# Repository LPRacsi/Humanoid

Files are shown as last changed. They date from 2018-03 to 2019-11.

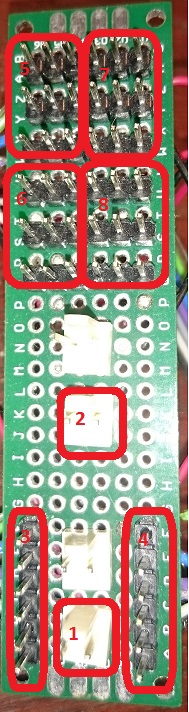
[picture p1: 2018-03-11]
Documentation/DSC_0448.JPG

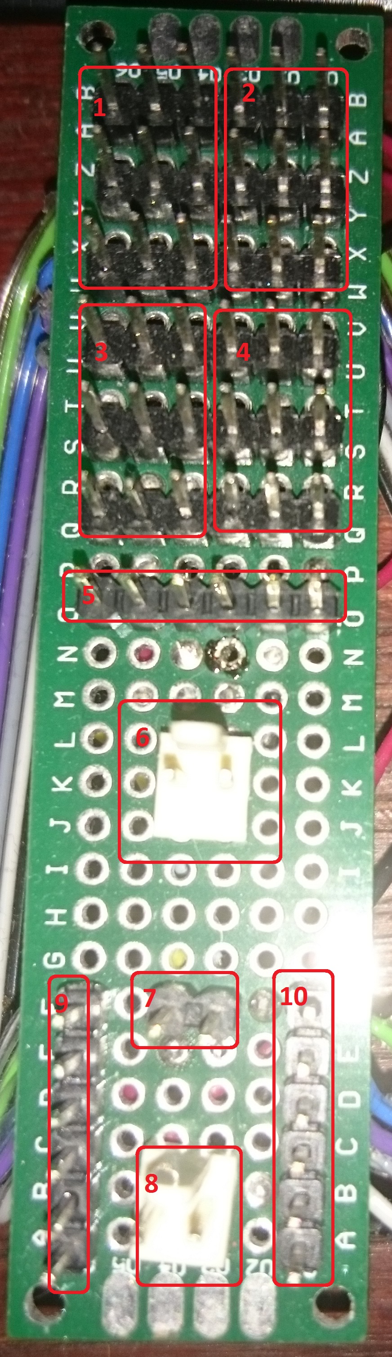
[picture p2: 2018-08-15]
Documentation/DSC_0721.JPG

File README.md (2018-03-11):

# Humanoid
# This project is about a humanoid robot, that has two 6 dof robotic arm on a tank chassis. The project is Arduino based
# Transmitter/controller
# The controller is based on a PS2 controller. There is an arduino nano, and an LCD display on it. The reansmission is done by a HC 12 433 mhz wilreless module.
# Receiver/the robot
# The Robot contains 2 arduino nano. 
# The first one is receiving the data through HC 12 and immediatelly sending it to the second arduino via serail port.Additionally the first arduino measures the battery voltage, and lit the indicator LEDs. The chain motor controlling is also a task for the first arduino,
# The second arduino is receiving data from the first and controlls the 6 DOF arm servos.
# Wiring can be seen on fritzing. Pin layout can be different.

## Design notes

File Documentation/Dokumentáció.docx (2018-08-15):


1. Táp 1
2. Táp 2
3. Jobb kar bemenet
4. Bal kar bemenet
5. Jobb kar kimenet táp 1 ről
6. Jobb kar kimenet táp 2 ről
7. Bal kar kimenet táp1 ről
8. Bal kar kimenet táp 2 ről

V2

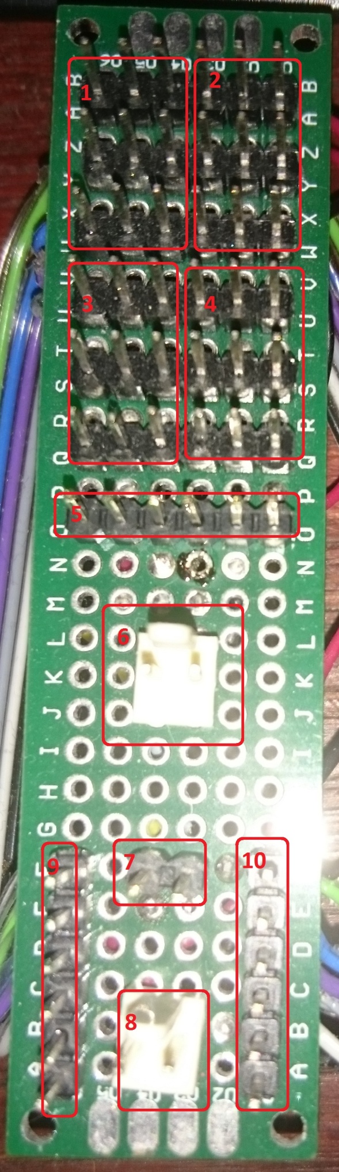
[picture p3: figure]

1. Jobb kar kimenet táp 1 ről
2. Bal kar kimenet táp1 ről
3. Jobb kar kimenet táp 2 ről
4. Bal kar kimenet táp 2 ről
5. Fej servo kimenetek
6. Táp2
7. Fej Servo bemenet
8. Táp1
9. Jobb kar bemenet
10. Bal kar bemmenet

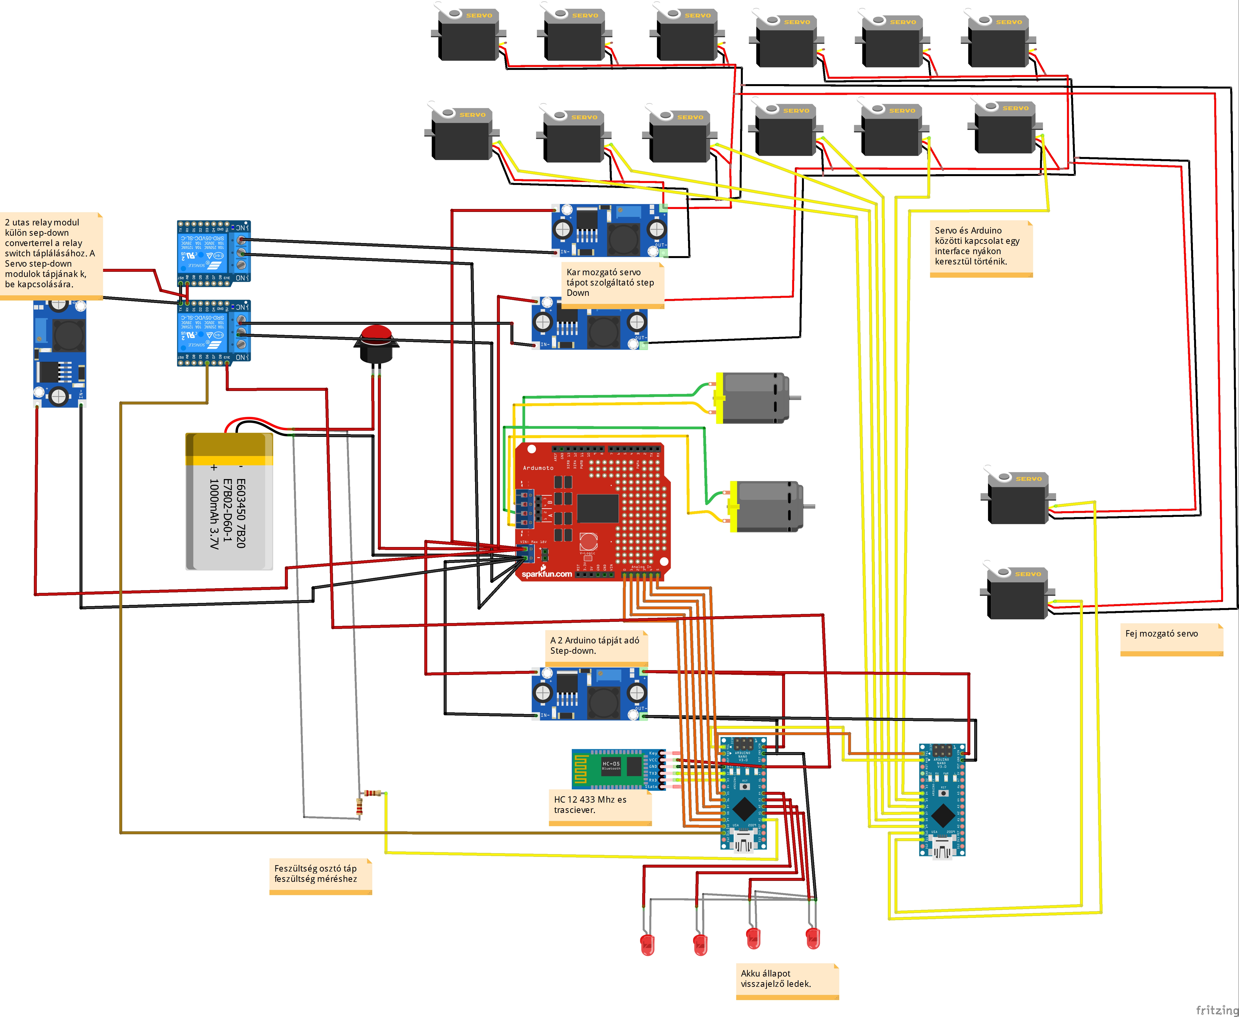
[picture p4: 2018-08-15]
Documentation/humanoid robot_bb.jpg

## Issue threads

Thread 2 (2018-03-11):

Power supply of the Servos should be changed

LPRacsi, 2018-03-11:
There should be a FET control for the servo power unit.  When the Arduino is uninitialized, the servo receives an invalid position request. The power for the servos should be enabled oly after Arduino initialization. With this method unwanted servo movements can be disabled.

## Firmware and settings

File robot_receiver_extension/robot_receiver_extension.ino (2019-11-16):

/* This code is used for receiving data via HC 12 and control a tank chassys arm servos
 * Author: Rácz László
*/
#include <SoftwareSerial.h>
#include <Servo.h>
#include <common_for_robot.h>
/*PIN definition*/
#define R_SER_RX_PIN          2
#define R_SER_TX_PIN          3
#define R_SHOULDER_SERVO_PIN  4
#define R_SHOULDER2_SERVO_PIN 5
#define R_ELBOW_SERVO_PIN     6
#define R_WRIST_SERVO_PIN     7
#define R_WRIST2_SERVO_PIN    8
#define R_HAND_SERVO_PIN      9
/**/
#define RECEIVED_ARRAY_ELEMENTS 16
#define RF2 0
#define RF1 1
#define LF2 2
#define LF1 3
#define BU4 4
#define BU3 5
#define BU2 6
#define BU1 7
#define UP0 8
#define RIG 9
#define LEF 10
#define DOW 11
#define RJX 12
#define RJY 13
#define LJX 14
#define LJY 15


/******Timing defines*************/
#define ARM_UPDATE_TIME   100

/**/
#define SERVO_MAX 175
#define SERVO_MIN 0

SoftwareSerial receiverSerial(R_SER_RX_PIN, R_SER_TX_PIN);
Servo rShoulder, rShoulder2, rElbow, rWrist, rWrist2, rHand;

char incomingByte;
String message, command;
int value, controllMode, controllModePrev, rShoulderPos, rShoulderPos2, rElbowPos, rWristPos, rWristPos2, rHandPos;
bool commandReceived, lostConnection;
unsigned short inputDataArray[RECEIVED_ARRAY_ELEMENTS];
unsigned long currTime, lastAliveTime, lastArmUpdateTime;

/***********************************************Function definitions***********************************************************/
/*
 * Function:    fillDataArrayWithInput
 * Parameter:   index: Index of input array
 *              value: Input array data to be stored
 * Description: Fill the input array with the received data
*/
void fillDataArrayWithInput(String index, int value){
  for (int i = 0; i < RECEIVED_ARRAY_ELEMENTS; i++){
    if (inputDataIDArray[i] == index){
      Serial.print("Update ");
      Serial.println(index);
      inputDataArray[i] = value;
    }
  }
}

/*
 * Function:    initInputDataArray
 * Description: Set init values as not pressed / not moved joystic
*/
void initInputDataArray(){
  int i;
  for (i = 0; i < 12; i++){
    inputDataArray[i] = 1; // Set 0 to the push buttons
  }
  for (i = 12; i < RECEIVED_ARRAY_ELEMENTS; i++){
    inputDataArray[i] = 512; // Set 512 for joystic 512 = middle
  }
}

/*
 * Function:    calcServoPosAI
 * Description: Calculates the new position of the corresponding servo 
 * Parameter:   inputDataArrayIndex: Index of input array
 *              pos:                 Actual position of he servo
 * Return:      New servo position
*/
int calcServoPosAI(int inputDataArrayIndex, int pos){
  int posMod;
  if (inputDataArray[inputDataArrayIndex] > 100 && inputDataArray[inputDataArrayIndex] < 923){
    posMod = 0;
  }
  if (inputDataArray[inputDataArrayIndex] >= 923){
    posMod = -1;
  }
  if (inputDataArray[inputDataArrayIndex] <= 100){
    posMod = 1;
  }    
  pos += (posMod * 2);
  if (pos >= SERVO_MAX){
    pos = SERVO_MAX; 
  }
  if (pos <= SERVO_MIN){
    pos = SERVO_MIN;
  }
  return pos;
}

/*
 * Function:    calcServoPosAI
 * Description: Calculates the new position of the corresponding servo 
 * Parameter:   inputDataArrayIndex: Index of input array
 *              pos:                 Actual position of he servo
 * Return:      New servo position
*/
int calcServoPosDI(int inputDataArrayIndex, int inputDataArrayIndex2, int pos){
  int posMod;
  if (inputDataArray[inputDataArrayIndex] == 1 && inputDataArray[inputDataArrayIndex2] == 1){
    posMod = 0;
  }
  if (inputDataArray[inputDataArrayIndex] == 0){
    posMod = -1;
  }
  if (inputDataArray[inputDataArrayIndex2] == 0){
    posMod = 1;
  }    
  pos += (posMod * 2);
  if (pos >= SERVO_MAX){
    pos = SERVO_MAX; 
  }
  if (pos <= SERVO_MIN){
    pos = SERVO_MIN;
  }
  return pos;
}

void setup() {
  Serial.begin(9600);
  //receiverSerial.begin(9600); 
  initInputDataArray();
  rShoulderPos = 30;
  rShoulderPos2 = 150;
  rElbowPos = 45;
  rWristPos = SERVO_MIN;
  rWristPos2 = 90;
  rHandPos = SERVO_MAX;
  controllMode = 0;
  controllModePrev = 0;
  commandReceived = false;
  message = "";
  incomingByte = "";
  command = "";
  lostConnection = false;
  currTime = millis();
  lastAliveTime = millis();
  lastArmUpdateTime = millis();
  rShoulder.attach(R_SHOULDER_SERVO_PIN);
  rShoulder2.attach(R_SHOULDER2_SERVO_PIN);
  rElbow.attach(R_ELBOW_SERVO_PIN);
  rWrist.attach(R_WRIST_SERVO_PIN);
  rWrist2.attach(R_WRIST2_SERVO_PIN);
  rHand.attach(R_HAND_SERVO_PIN);
  rShoulder.write(rShoulderPos);
  rShoulder2.write(rShoulderPos2);
  rElbow.write(rElbowPos);
  rWrist.write(rWristPos);
  rWrist2.write(rWristPos2);
  rHand.write(rHandPos);
}

void loop() {
  if(Serial.available() > 0){
    incomingByte = Serial.read();
    //Serial.print("incomingByte :");
    //Serial.println(incomingByte);
    if (isWhitespace(incomingByte)){
      /*Do nothing here*/
    }else{
      //Serial.println(incomingByte);
      if (incomingByte == '@'){//The control sign
        command = message.substring(0,1);
        value = message.substring(1).toInt();
        message = "";
        if (alive == command || modS == command){
          //Serial.println("alive or mode!");        
          commandReceived = true;
        }else{      
          for (int l =0; l < (sizeof(inputDataIDArray)/ sizeof(inputDataIDArray[0])); l++){          
            /*Serial.print("(sizeof(inputDataIDArray)/ sizeof(inputDataIDArray[0])) ");
            Serial.println((sizeof(inputDataIDArray)/ sizeof(inputDataIDArray[0])));          
            Serial.print("l ");
            Serial.println(l);          
            Serial.print("inputDataIDArray[l] ");
            Serial.println(inputDataIDArray[l]);
            Serial.print("command ");
            Serial.println(command);*/
            if (inputDataIDArray[l] == command){
              //Serial.println("Command foumnd");
              commandReceived = true;
              break;
            }
          }  
        }  
        if (commandReceived && 0 <= value && 1023 >= value){
          //Serial.println("Range found!");
          commandReceived = true;
        }else{
          commandReceived = false;
        }
      }else{
        commandReceived = false;
        message += incomingByte;
      }
    }
  }
  if (commandReceived){
    lastAliveTime = millis();
    if (lostConnection){
      controllMode = controllModePrev;
      lostConnection = false;
    }
    if (command == "Y"){
      controllMode = value;
      Serial.print("controllMode :");
      Serial.println(controllMode); 
      //receiverSerial.print("OK");
      //receiverSerial.print(" ");
    }
    else if (command == "X"){
      /*Do nothing here*/
    }
    else {
      /*Serial.println("Aatfeltoltes--------------------------------------------");
      Serial.print("command ");
      Serial.println(command);
      Serial.print("value ");
      Serial.println(value);*/
      fillDataArrayWithInput(command, value);
    }
    commandReceived = false;
  }

  currTime = millis();
  
  if (currTime - lastAliveTime > CONN_LOST_TIME && !lostConnection){
    controllModePrev = controllMode;
    controllMode = DEFAULT_MODE;
    lostConnection = true;
    delay(50);
  }
  //Serial.print("controllMode :");
  //Serial.println(controllMode);    
  switch(controllMode){
    case DRIVE_ONLY:
      /*Do nothing here*/
    break;
    case R_ARM_ONLY:
    case R_ARM_AND_DRIVE:
      if (currTime - lastArmUpdateTime > ARM_UPDATE_TIME){
        rShoulderPos = calcServoPosAI(RJX, rShoulderPos);
        rShoulder.write(rShoulderPos);
        rShoulderPos2 = calcServoPosAI(RJY, rShoulderPos2);
        rShoulder2.write(rShoulderPos2);
        rElbowPos = calcServoPosDI(LF1, LF2, rElbowPos);
        rElbow.write(rElbowPos);
        rWristPos = calcServoPosAI(LJX, rWristPos);
        rWrist.write(rWristPos);
        rWristPos2 = calcServoPosAI(LJY, rWristPos2);
        rWrist2.write(rWristPos2);
        rHandPos = calcServoPosDI(RF1, RF2, rHandPos);
        rHand.write(rHandPos);
        lastArmUpdateTime = millis();
      }  
    break;
    default:
      /*Do nothing here*/
    break;
    
  }
}

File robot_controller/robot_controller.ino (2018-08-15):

/* This code is used for sending the converted PS2 data through HC 12
 * Author: Rácz László
*/

#include <SoftwareSerial.h>
#include <Wire.h>
#include <LCD.h>
#include <LiquidCrystal_I2C.h>
#include <common_for_robot.h>

#define I2C_ADDR           0x27        //Define I2C Address where the PCF8574A is
#define BACKLIGHT_PIN      3
#define En_pin             2
#define Rw_pin             1
#define Rs_pin             0
#define D4_pin             4
#define D5_pin             5
#define D6_pin             6
#define D7_pin             7

LiquidCrystal_I2C      lcd(I2C_ADDR, En_pin,Rw_pin,Rs_pin,D4_pin,D5_pin,D6_pin,D7_pin);

/*Remote controller modes*/
#define SELECT 1
#define NORMAL 0

#define ALIVE_INDEX 20
#define MOD_INDEX   30

#define MODE_MAX_INDEX      5
#define SENT_ARRAY_ELEMENTS 16
#define ALIVE_SEND_TIME     1500
#define CONN_LOST_TIME      3500
/*Pin selections*/
#define rightJoyXPin  A0
#define rightJoyYPin  A1
#define leftJoyXPin   A2
#define leftJoyYPin   A3
#define up            3
#define right         4
#define down          5
#define left          6
#define button4       7
#define button3       8
#define button2       9
#define button1       10
#define rightFront2   2
#define rightFront1   12
#define leftFront2    A6
#define leftFront1    A7
#define mode          11


short modeCounter, dataSendSelect, remoteMode, modeStringIndex, modeStringIndexPrev, value, prevReceivedValue, resendNum;
bool modeRead, upRead, downRead, upReadPrev, downReadPrev, modeChange, hasNewIndex, connectionLost, devTextChange;
char* modeString[MODE_MAX_INDEX] = {"Drive only!",//0 
                                    "R.arm only!",//1 
                                    "L.arm only!",//2 
                                    "R.arm&drive!",//3 
                                    "L.arm&drive!"};//4
                                    
/*char* inputDataIDArray[] = {"rF2", "rF1", "lF2", "lF1",
                            "bu4", "bu3", "bu2", "bu1",
                            "up0", "rig", "lef", "dow",
                            "rJX", "rJY", "lJX", "lJY",};*/
unsigned short inputDataArray[SENT_ARRAY_ELEMENTS], inputDataArray_old[SENT_ARRAY_ELEMENTS],indexArray[SENT_ARRAY_ELEMENTS];
unsigned long lastSendTime, currTime, lastSelectTime, lastModeTime, prevSentAliveTime, lastReceivedAliveTime;
unsigned long cycleTime = 100;
unsigned long selectCycleTime = 250;

char input;
String message, command;
bool commandReceived;

/***********************************************Function definitions***********************************************************/

/*
 * Function:    readFromInput
 * Description: Reading the input from buttons.
 *              Filling the inputDataArray with the data.
*/
void readFromInput(){
  int lf1, lf2;
  lf2 = analogRead(leftFront2);
  lf1 = analogRead(leftFront1);
  inputDataArray[0] = digitalRead(rightFront2); 
  inputDataArray[1] = digitalRead(rightFront1);
  inputDataArray[2] = (lf2 > 512) ? 1: 0; //convert to bool
  inputDataArray[3] = (lf1 > 512) ? 1: 0; //convert to bool
  inputDataArray[4] = digitalRead(button4);
  inputDataArray[5] = digitalRead(button3); 
  inputDataArray[6] = digitalRead(button2);
  inputDataArray[7] = digitalRead(button1); 
  inputDataArray[8] = digitalRead(up);
  inputDataArray[9] = digitalRead(right); 
  inputDataArray[10] = digitalRead(left); 
  inputDataArray[11] = digitalRead(down); 
  inputDataArray[12] = joysticToRange(analogRead(rightJoyXPin)); 
  inputDataArray[13] = joysticToRange(analogRead(rightJoyYPin)); 
  inputDataArray[14] = joysticToRange(analogRead(leftJoyXPin)); 
  inputDataArray[15] = joysticToRange(analogRead(leftJoyYPin));
}

/*
 * Function:    joysticToRange
 * Parameter:   chord - The input joystic chordinate 0-1023
 * Return value:Returning joystic chordinate in ranged value
 * Description: Converting the input choordinates into fixed range values.
*/
unsigned short joysticToRange(unsigned short chord){
  unsigned short retVal = 0;
  if (0 <= chord && chord <= 204){
    retVal = 0;
  }
  if (205 <= chord && chord <= 409){
    retVal = 307;
  }
  if (410 <= chord && chord <= 614){
    retVal = 512;
  }
  if (615 <= chord && chord <= 819){
    retVal = 717;
  }
  if (820 <= chord && chord <= 1023){
    retVal = 1023;
  }
  return retVal;
}
/*
 * Function:    saveOldInput
 * Description: Saving the previusly readed input data to inputDataArray_old.
*/
void saveOldInput(){
  for(int j = 0; j < SENT_ARRAY_ELEMENTS; j++){
    inputDataArray_old[j] = inputDataArray[j];
  }
}

/*
 * Function:    sendData
 * Parameter:   index: The index of data ID and data
 * Description: Sending the ID of the data and the data itself to the receiver. 
*/
void sendData(int index){
  if (index == ALIVE_INDEX){// nagyobb mint a inputDataIDArray maximuma
    Serial.print("X1");
    Serial.print('@');
    Serial.print(" ");
  }else if (index >= MOD_INDEX && index <= MOD_INDEX+4){// kell egy shift a 0-4 be pl 30 és akkor 
    Serial.print("Y");
    Serial.print(index-MOD_INDEX);
    Serial.print('@');
    Serial.print(" ");  
  }else{ // ha nem mod váltás és nem alive küldés
    Serial.print(inputDataIDArray[index]);
    Serial.print(inputDataArray[index]);
    Serial.print('@');
    Serial.print(" ");
  }
  delay(20);
  prevSentAliveTime = millis();
}

/*
 * Function:    compareChanges
 * Description: Comparing the old button states and the new states, and storing the changes in indexArray
*/
void compareChanges(){
  int k = 0;
  for(int j = 0; j < SENT_ARRAY_ELEMENTS; j++){
    if (j > 11){
      if (5 < abs(inputDataArray_old[j] - inputDataArray[j])){
        indexArray[k] = j;
        k++;
        hasNewIndex = true;
      }
    }else
    if (inputDataArray_old[j] != inputDataArray[j]){
      indexArray[k] = j;
      k++;
      hasNewIndex = true;
    }
  }
}

/*
 * Function:    clearIndexArray
 * Description: Clearing the indexes in indexArray
*/
void clearIndexArray(){
  for(int j = 0; j < SENT_ARRAY_ELEMENTS; j++){
    indexArray[j] = 0;
    hasNewIndex = false;
  }
}


/*
 * Function:    handleLCD
 * Parameter:   row: The row to be modified on LCD
 *              column: The start column of the printed string
 *              message: The massage to be printed
 *              clearRow: Clear the row if requested
 * Description: Handle requests to LCD writes.
*/
void handleLCD(int row, int column, String message, bool clearRow){
  if (clearRow){
    lcd.setCursor(0,row);
    lcd.print("                "); //Clearing the selected row
  }
  lcd.setCursor(column,row);
  lcd.print(message);
}

/*
 * Function:    initInputDataArray
 * Description: Set init values as not pressed / not moved joystic
*/
void initInputDataArray(){
  int i;
  for (i = 0; i < 12; i++){
    inputDataArray[i] = 1; // Set 0 to the push buttons
  }
  for (i = 12; i < SENT_ARRAY_ELEMENTS; i++){
    inputDataArray[i] = 512; // Set 512 for joystic 512 = middle
  }
}
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

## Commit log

2018-03-11 Updated with documentation
    [humanoid robot.fzz]
2018-03-11 Readme updated, interface board image added
2018-08-15 Communication stabilized (Master-slave concept) Ducumentation and circuit diagram updated
    [humanoid robot.fzz]
